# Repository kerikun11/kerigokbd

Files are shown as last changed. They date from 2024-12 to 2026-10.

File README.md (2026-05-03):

# KERIgoKBD (KERI's Ergonomic Keyboard)

けりの自作キーボードの設計データ。

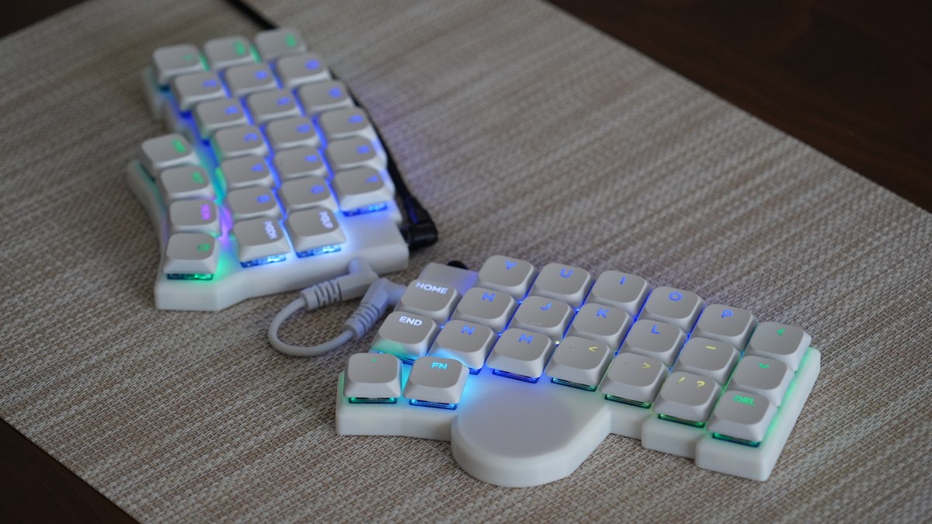
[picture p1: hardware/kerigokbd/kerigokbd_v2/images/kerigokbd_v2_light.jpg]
KERIgoKBD v2


```tree
kerigokbd/
├── hardware/
│   ├── kerigokbd/      # KERIgoKBD common PCB/case parts
│   └── README.md       # Hardware parts and compatibility table
├── software/
│   └── qmk/
│       ├── firmware/   # QMK Firmware for VIA (git submodule)
│       ├── keyboards/  # Keyboard entries for QMK Firmware
│       ├── qmk.sh      # build script
│       └── README.md   # build manual
├── .gitmodules
└── README.md
```

## 作品一覧

ハードウェア部品とファームウェアの対応は [`hardware/README.md`](./hardware/README.md) に記載。

| 作品 | コメント |
| :--- | :--- |
| [KERIgoKBD v1](./hardware/kerigokbd/kerigokbd_v1/) | はじめての自作エルゴノミックキーボード。 |
| [KERIgoKBD v2](./hardware/kerigokbd/kerigokbd_v2/) | KERIgoKBD v1 にトラックパッドを追加した構成。 |
| [KERIgoKBD Corne v4](./hardware/kerigokbd_corne_v4/) | Corne V4 Chocolate のケースとファームウェアをカスタマイズしたもの。 |
| Keyball44 RP2040 | Keyball44 のマイコンボードを RP2040 Pro Micro に差し替えたもの。 |

## KERIgoKBD v1

[けり](https://github.com/kerikun11)のはじめての自作キーボード。

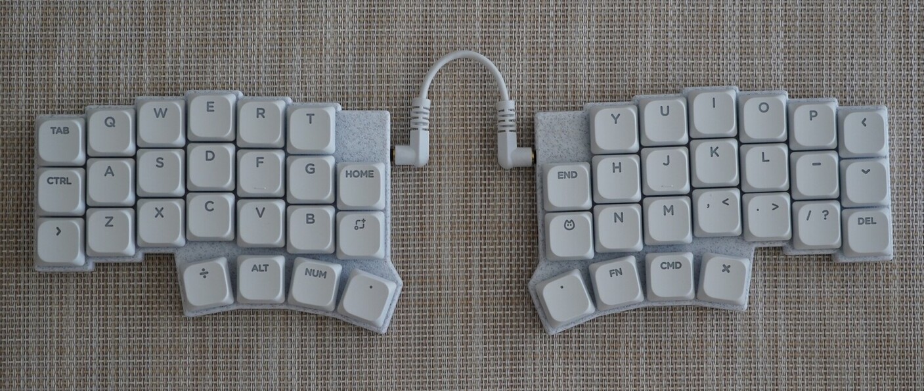
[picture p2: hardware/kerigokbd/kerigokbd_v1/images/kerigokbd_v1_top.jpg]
KERIgoKBD v1


## KERIgoKBD v2

KERIgoKBD v1 の右手側にトラックパッドを追加した構成。

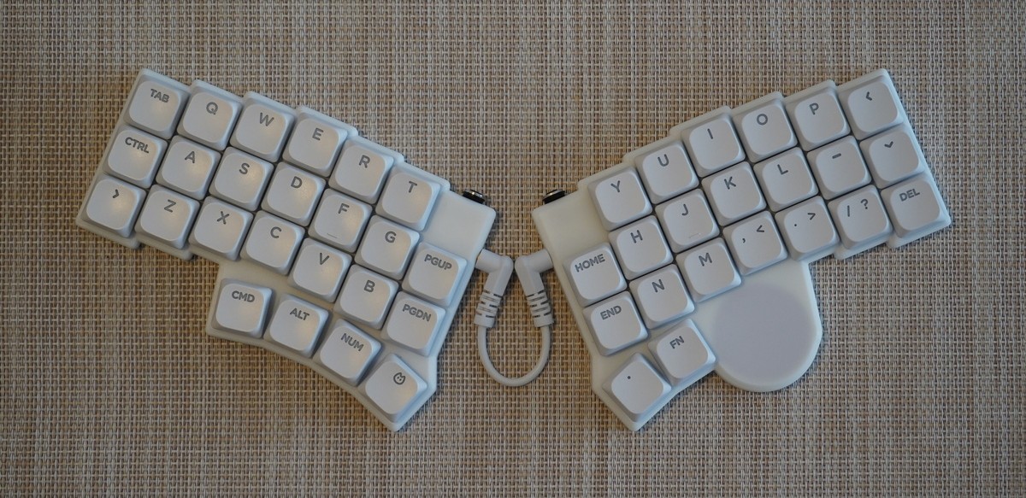
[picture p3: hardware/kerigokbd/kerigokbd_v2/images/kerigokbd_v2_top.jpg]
KERIgoKBD v2


## KERIgoKBD Corne v4

[foostan](https://github.com/foostan)さんの[Corne V4 Chocolate](https://github.com/foostan/crkbd)のケースとファームウェアをカスタマイズしたもの。

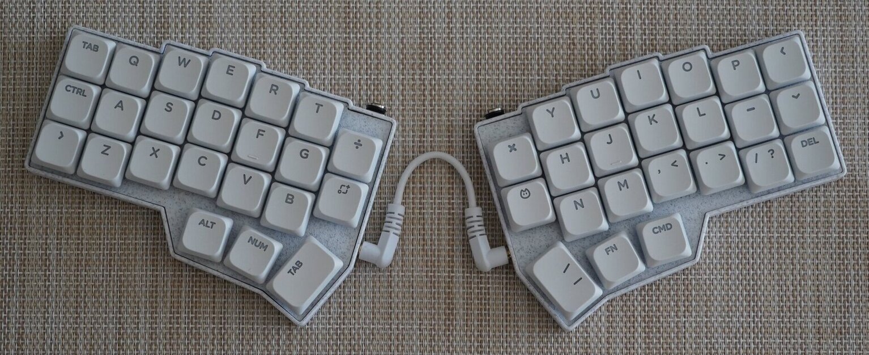
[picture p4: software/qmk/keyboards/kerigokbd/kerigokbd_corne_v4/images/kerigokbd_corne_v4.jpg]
KERIgoKBD Corne V4


## Keyball44 RP2040

[Yowkees](https://github.com/Yowkees)さんの[Keyball44](https://github.com/Yowkees/keyball)のマイコンボードを `RP2040 Pro Micro` に差し替えたもの。

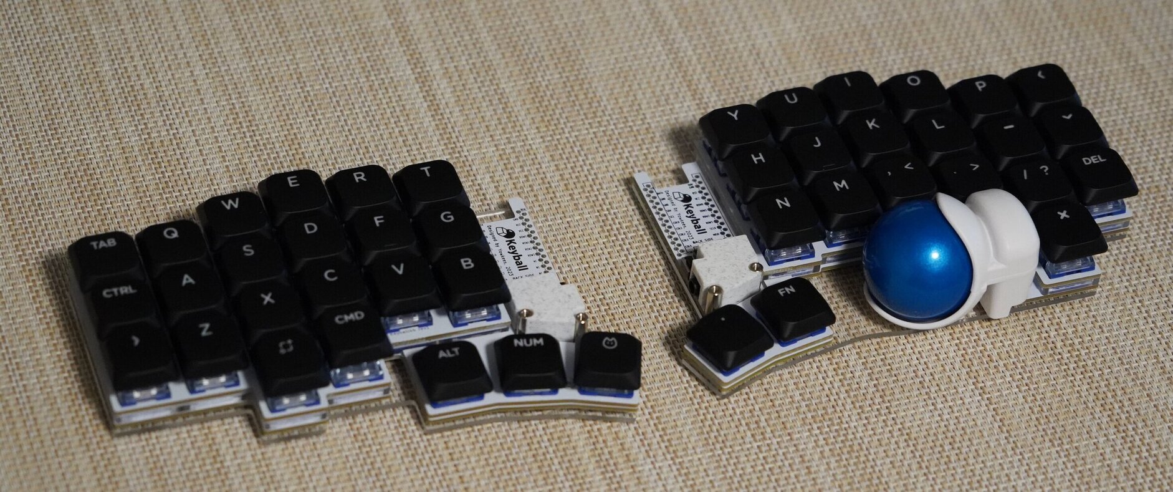
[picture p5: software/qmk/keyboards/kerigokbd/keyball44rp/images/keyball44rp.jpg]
Keyball44rp


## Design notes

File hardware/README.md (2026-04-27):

# Hardware

KERIgoKBD のハードウェア設計データ。ここでは PCB、ケースなどの物理パーツを作品ごとに分離して管理する。

## 対応表

| 作品 | PCB | ケース | ファームウェア | メモ |
| :--- | :--- | :--- | :--- | :--- |
| [KERIgoKBD v1](./kerigokbd/kerigokbd_v1/) | [`pcb_20260222`](./kerigokbd/pcb_20260222/) | [`case_20260222`](./kerigokbd/case_20260222/) | [`kerigokbd_v1`](../software/qmk/keyboards/kerigokbd/kerigokbd_v1) | 標準構成 |
| [KERIgoKBD v2](./kerigokbd/kerigokbd_v2/) | [`pcb_20260222`](./kerigokbd/pcb_20260222/) | [`case_20260222_trackpad`](./kerigokbd/case_20260222_trackpad/) | [`kerigokbd_v2`](../software/qmk/keyboards/kerigokbd/kerigokbd_v2) | 右手にトラックパッド追加 |

## KERIgoKBD パーツ

### PCB

| パーツ | 内容 |
| :--- | :--- |
| [`pcb_20241229`](./kerigokbd/pcb_20241229/) | v1.0 初版。I2Cピンアサインにミスあり。 |
| [`pcb_20250208`](./kerigokbd/pcb_20250208/) | v1.1 I2Cピンアサイン修正版。 |
| [`pcb_20260222`](./kerigokbd/pcb_20260222/) | v1.2 小型版。v1/v2 共通 PCB。 |

### ケース

| パーツ | 内容 |
| :--- | :--- |
| [`case_20250208`](./kerigokbd/case_20250208/) | PCB v1.0 と v1.1 向けのケース。 |
| [`case_20260222`](./kerigokbd/case_20260222/) | PCB v1.2 向けケース。 |
| [`case_20260222_trackpad`](./kerigokbd/case_20260222_trackpad/) | PCB v1.2 向け、トラックパッド対応ケース。 |

## その他

- [`kerigokbd_corne_v4`](./kerigokbd_corne_v4/) は Corne V4 Chocolate のカスタムケース。

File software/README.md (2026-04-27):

# ソフトウェア

ファームウェアのビルドと書き込みの方法

## 前提

- [QMKコマンド](https://docs.qmk.fm/newbs_getting_started)がインストールされていること
- シンボリックリンクが作成できる環境であること

## ソースコードの取得と初回セットアップ

カスタムファームウェアのディレクトリをQMKリポジトリの中にシンボリックで追加して、不要な差分が表示されないように無視設定を行う。

```sh
## clone this repository with submodules
git clone --recursive https://github.com/kerikun11/kerigokbd.git
cd kerigokbd/software
```

下記コマンドでQMK Firmwareの `keyboards` ディレクトリ内へカスタムキーボードへのリンクを作成する。

```sh
## setup only
./qmk/qmk.sh -s
```

## ビルドと書き込み

QMKファームウェアのディレクトリでqmkコマンドを実行する。

```sh
cd ./qmk/firmware
## setup
qmk setup
## clean
qmk clean
## compile
qmk compile -kb kerigokbd/kerigokbd_v1/pcb_20260222 -km via
qmk compile -kb kerigokbd/kerigokbd_v2/pcb_20260222 -km via
## compile and flash
qmk flash -kb kerigokbd/kerigokbd_v1/pcb_20260222 -km via
qmk flash -kb kerigokbd/kerigokbd_v2/pcb_20260222 -km via
```

または下記スクリプトでも実行できる。

```sh
## compile
./qmk/qmk.sh
## compile and flash
./qmk/qmk.sh -f
## clean, compile, and flash
./qmk/qmk.sh -c -f
```

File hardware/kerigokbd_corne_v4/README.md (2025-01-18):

# KERIgoKBD Corne V4



[foostan](https://github.com/foostan)さんの[Corne V4 Chocolate](https://github.com/foostan/crkbd)のケースをカスタマイズしたもの。

## ケース

Autodesk Fusionで設計。Bambu Lab P1S PLA White Marbleで印刷。

- 設計データ(ボトムケース)：[cases](https://github.com/foostan/crkbd/tree/main/cases/3x6) by [foostan](https://github.com/foostan)さん
- 設計データ(フロントパネル)：[case](./case/)

## ライセンス

この作品は [クリエイティブ・コモンズ 表示-非営利 4.0 国際 ライセンス](https://creativecommons.org/licenses/by-nc/4.0/deed.ja)の下に提供されています。

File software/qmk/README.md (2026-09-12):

# ソフトウェア

ファームウェアのビルドと書き込みの方法

## 前提

- [QMKコマンド](https://docs.qmk.fm/newbs_getting_started)がインストールされていること
- シンボリックリンクが作成できる環境であること

## ソースコードの取得と初回セットアップ

カスタムファームウェアのディレクトリをQMKリポジトリの中にシンボリックで追加して、不要な差分が表示されないように無視設定を行う。

```sh
## clone this repository with submodules
git clone --recursive https://github.com/kerikun11/kerigokbd.git
cd kerigokbd/software/qmk
```

下記コマンドでQMK Firmwareの `keyboards` ディレクトリ内へカスタムキーボードへのリンクを作成する。

```sh
## setup only
./qmk.sh -s
```

## ビルドと書き込み

QMKファームウェアのディレクトリでqmkコマンドを実行する。

```sh
cd ./firmware
## setup
qmk setup
## clean
qmk clean
## compile
qmk compile -kb kerigokbd/kerigokbd_v1/pcb_20260222 -km via
qmk compile -kb kerigokbd/kerigokbd_v2/pcb_20260222 -km via
## compile and flash
qmk flash -kb kerigokbd/kerigokbd_v1/pcb_20260222 -km via
qmk flash -kb kerigokbd/kerigokbd_v2/pcb_20260222 -km via
```

または下記スクリプトでも実行できる。

```sh
## compile
./qmk.sh
## compile and flash
./qmk.sh -f
## clean, compile, and flash
./qmk.sh -c -f
```

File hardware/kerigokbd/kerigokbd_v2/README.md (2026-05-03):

# KERIgoKBD v2 Hardware



けりの人間工学キーボード第2版のハードウェア構成。

KERIgoKBD v1.2 PCB を使用し、右手側に Cirque トラックパッドを追加した構成。

KERIgoKBD v2

## 特徴

- 肩への負担を和らげる **左右分離** キーボード
- 手の形に合わせた **カラムスタッガード** の独自キー配置
- 左手24キー、右手22キー、合計46キーの **40%レイアウト**
- レイヤ切り替えに使いやすい **親指キー** を左4個、右2個搭載
- 右手側に **Cirque トラックパッド** を統合
- **ロープロファイルキースイッチ** による薄型・軽量設計
- 全キー **RGB バックライト** でレイヤやキー種別を表示
- **QMK Firmware / VIA / Pointing Device** に対応

KERIgoKBD v2 Top

## 構成

| 項目 | 使用パーツ |
| :--- | :--- |
| PCB | [`pcb_20260222`](../pcb_20260222/) |
| 左手ケース | [`case_20260222`](../case_20260222/) |
| 右手ケース | [`case_20260222_trackpad`](../case_20260222_trackpad/) |
| ファームウェア | [`kerigokbd/kerigokbd_v2/pcb_20260222`](../../../software/qmk/keyboards/kerigokbd/kerigokbd_v2/pcb_20260222/) |
| Keyboard Layout Editor | [KERIgoKBD v2 - Keyboard Layout Editor](https://www.keyboard-layout-editor.com/#/gists/0d82236d0943d0b74055119b50123c59) |

## スペック

| 項目 | 内容 |
| :--- | :--- |
| マイコン | [RP2040](https://www.raspberrypi.com/products/rp2040/specifications/) (Cortex-M0+ 133MHz x2, 264kB SRAM) |
| フラッシュ | [W25Q16JVUXIQ](https://www.digikey.jp/ja/products/detail/winbond-electronics/W25Q16JVUXIQ-TR/) (2MB) |
| キースイッチ | [Kailh Deep Sea Silent Mini Low Profile Key Switch (Linear)](https://www.aliexpress.com/item/1005007364820059.html) |
| キーキャップ | [NuPhy nSA Keycaps (Shine-through White)](https://www.aliexpress.com/item/1005006384968360.html) |
| キーソケット | [Hot Swap Socket for Kailh 1350 Chocolate](https://www.aliexpress.com/item/1005006610157756.html) |
| トラックパッド | [Cirque Trackpad TM035035](https://mou.sr/48nN2VQ) |
| 左右接続ケーブル | [3.5mm AUX Cable (White 3 Pole 10cm)](https://www.aliexpress.com/item/1005002484746676.html) |
| USBケーブル | [USLION Magnetic USB Type-C ケーブル](https://www.aliexpress.com/item/1005006136597761.html) |
| 滑り止めシート | [GRIPLUS ホワイト フリーカット](http://www.amazon.co.jp/dp/B08XHMGPWW/) |

## ライセンス

This work is licensed under a [Creative Commons Attribution-NonCommercial 4.0 International License](https://creativecommons.org/licenses/by-nc/4.0/).

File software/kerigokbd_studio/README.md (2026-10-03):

# KERIgoKBD Studio

- KERIgoKBD v1/v2・KERIgoKBD Corne V4・KERIgoKBD Keyball44の各レイヤーのキーマップを一枚の早見表として表示しつつ、実機に接続した状態でリアルタイムに編集できるWebアプリ(WebHID + QMK VIAプロトコル)。
- GitHub Pagesで公開中: <https://www.kerislab.jp/kerigokbd/>

## 主な機能

- **キーボード切り替え**
  - 設定の「デバイス」にある「キーボード」でv1・v2・Corne V4・Keyball44を切り替え。物理キー配置・トラックパッド有無・Trackpadレイヤー有無も合わせて切り替わる。オートマウスレイヤー(`KGL_AM`)はポインティングデバイスに合わせてv2ではTrackpad、Keyball44ではTrackballと表示する(`build_layout.py`の`label`)
  - 実機に接続すると(ページ読み込み時の自動再接続を含む)、USBのVID/PID(`info.json`/`keyboard.json`の`usb`)から機種を判定して自動で切り替える。未書き込みの変更があるときは破棄してよいか確認する
- **早見表 / 編集画面の切り替え**
  - 設定ペイン右上の「表示 | 編集」で、全レイヤー重ね合わせの早見表(デフォルト表示)と、実機の値を書き換える編集画面を切り替える。接続前はGitHub最新版(mainの`default/keymap.c`、`defaults-*.js`)、接続後は実機の現在の値を表示
  - 設定ペインはモードに合わせて切り替わる。「デバイス」(キーボード選択・接続状態・接続/切断の切り替えボタン・再読込)は共通で、表示モードでは「表示するレイヤー」「書き出し」(PNG)、編集モードでは「書き出し・初期化」(keymap.c・GitHub最新版に更新・初期状態にリセット)を表示する
- **レイヤー別のキーマップ表示**
  - Main/Num/Fn/Extra/Trackpad(v2)・Trackball(Keyball44)の割り当てを1枚の早見表に色分け表示。長押し時の割り当て(Hold)は下端に表示
- **レイヤー表示のON/OFF切り替え**
  - 表示モードの設定「表示するレイヤー」のトグルでNum・Fn・Extra・Trackpadレイヤを個別に表示/非表示にできる。オフにしたレイヤーは凡例と、そのレイヤーを指す長押しラベル(Trackpadはトラックパッド上のアイコンも)からも消える
- **操作アイコン表示**
  - マウスクリック(左/右/中)・ポインタ移動・ホイール移動・スクロールモードをアイコンと凡例で表示
- **実機との同期(WebHID + VIA)**
  - 「実機に接続」で`via`キーマップを書き込んだ実機とペアリングし、現在のキーマップを読み込む
  - 編集画面でキーを選び、キーコードピッカーから値を選ぶと「未書き込みの変更」として保持する(点線表示、レイヤータブにも印)。「実機に書き込む」を押すまで実機には反映されず、レイヤータブ右側の「未書き込み N件」で開く一覧の各キーの「取り消す」(キー単位)・「すべて破棄」、またはピッカーの「このキーの変更を取り消す」で元に戻せる。一覧の項目を押すとそのキーを選択する
  - 編集画面の構成: レイヤータブと変更バー(未書き込み件数・すべて破棄・実機に書き込む)が1行、その下にキーボード、「凡例」、キーコードピッカー。ピッカーは常に同じ位置にあり、未接続・未選択のときは案内を表示する。選択中のキーをもう一度クリックする、キー・ピッカー以外の場所をクリックする、またはEscで選択を解除する
  - 書き込み後は該当レイヤーを実機から読み直して照合し、実機に反映されなかった変更は未書き込みのまま残す
  - 未書き込みの変更がある状態での再読込・キーボード切り替え・ページ離脱は確認を挟む
  - 長押し: ピッカーの「長押し」行で「なし / MO (レイヤーのみ) / LT (タップ+レイヤー) / MT (タップ+修飾キー)」を選ぶ。MO・LTはレイヤーのチップ、MTは修飾キーのチェックボックス(「右側 (R)」で右側)で指定し、選んだ時点で現在のキーに反映される。LT・MTは現在のタップキーをそのまま包み、以降に選んだ基本キーがタップ動作になる。MOはタップ動作を持たないため、キーを選ぶと通常のキーに戻る。TO・DF・TGなどは「レイヤー動作」タブから割り当てる(`TO (Main)` のように動作×レイヤーごとに1ボタン)。今のレイヤーを固定するLayer Lock(`QK_LLCK`)は「特殊」タブから割り当てる(ファームウェアの`LAYER_LOCK_ENABLE = yes`が必要)
  - 同時押し: ピッカーの「同時押し」行のCtrl/Shift/Alt/Winのチェックボックス(「右側 (R)」で右側)で、`LALT(KC_PSCR)`のように修飾キーと同時に送るキーにする。LT・MT・MOとは同時に指定できない(QMKのキーコード仕様)
  - Any: 「Any」タブで16進数(`0x4329`)や`keymap.c`と同じ書式の式(`LT(KGL_EXT, KC_ESC)`・`LALT(KC_PSCR)`・`LCTL_T(KC_A)`・`MT(MOD_LCTL | MOD_LSFT, KC_A)`・`MO(1)`・`KG_ESC`など)を入力して割り当てる。入力中に値と表示を確認でき、不正な式は理由を表示する
  - 編集画面では割り当ての種類を色分けし、凡例に表示する(LT: 青、MO: 紫、TO: 黄土、MT: 緑。修飾キー同時押しは`Ctrl+`のような表記で分かるため色分けしない)
  - キーの交換: キーを選んでピッカー上部の「交換」を押し、交換先のキーをクリックすると、2つのキーの割り当てを入れ替えて未書き込みの変更にする。レイヤータブで切り替えれば別のレイヤーのキーとも交換できる。交換元をもう一度クリック、Esc、または「交換を中止」で取りやめる
  - キーを選ぶと、ピッカー上部の選択中のキー表示に、かっこ書きでそのキーの説明(記号の実際の文字「^」、特殊キーの機能、LT・MTなどのタップ/長押しの動作)を表示する(`keycodes/keycode-description.js`)
  - 編集画面では、GitHub最新版(mainの`default/keymap.c`)から変更されたキーの右上に赤の丸印を表示する
  - 「再読込」で実機の現在値を読み直す。接続中は「実機に接続」ボタンが「切断」に切り替わる
  - 「実機に書き込む」(編集画面の変更バーにあり、未書き込みの変更がないときは押せない。未接続の場合は理由を表示)で未書き込みの変更を実機に反映する
- **左右のキーマップをそろえる**
  - 片側(例: 左)を接続して編集・書き込み後、USBをもう片側(右)に挿し直して「実機に接続」すると、エディタの内容と実機の値が異なる場合に「エディタの内容を残す / 実機の値を読み込む」を確認する
  - 「エディタの内容を残す」を選ぶと差分が未書き込みの変更になり、「実機に書き込む」でその実機に反映される(書き込むまで実機は変更されない)
- **keymap.cへの書き出し**
  - 実機の現在のキーマップから、`keymap.c`に手動で反映できるC言語ソースを生成してコピーする
- **mainの最新版レイアウトへの更新**
  - 選択した機種の`keymaps/default/keymap.c`を数値化したデータ(このページ自身にバンドル済み)で実機の全レイヤーを上書きする。早見表の接続前表示と同じデータなので、更新のためにネットワークへ取得しにいくことはない
  - 実機のファームウェアが報告するレイヤー数より最新版のレイヤー数が多い場合は書き込まない(ファームウェアが古く、mainで追加された新しいレイヤーに未対応な場合など)。少ない場合(v2のファームウェアにv1の最新版を書き込む場合など)は、最新版にあるレイヤーだけを書き込み、実機の残りのレイヤーは変更しない
  - 更新前に実機の値を保存し、書き込み後に再読込して照合する。失敗時は元の値への復元を試み、USB切断などで復元できない場合はその旨を表示する
- **ファームウェア初期状態へのリセット**
  - 実機のファームウェアに組み込まれた初期値に、実機のキーマップを戻す
- **PNG画像エクスポート**
  - 早見表(トグルで隠したレイヤーはそのまま反映)をPNGとしてクリップボードへコピー、またはファイルへダウンロードできる

## 前提条件

- **ブラウザ**: WebHIDに対応したChromium系ブラウザ(Chrome / Edge)。Firefox / Safariは非対応。
- **ファームウェア**: `via`キーマップ(`VIA_ENABLE = yes`)を書き込んだ実機。`default`キーマップにはRAW HIDが無いため接続できない。

VIAのdynamic keymap機能は既定では4レイヤーまでしか公開しない(`quantum/dynamic_keymap.h`の`DYNAMIC_KEYMAP_LAYER_COUNT`既定値)が、KERIgoKBDの`info.json`側で`dynamic_keymap.layer_count`(v2・Keyball44は7、v1・Corne V4は6)を既に指定済みで、QMKのビルド時に`DYNAMIC_KEYMAP_LAYER_COUNT`へ自動変換される(`data/mappings/info_config.hjson`参照)。追加のファームウェア変更は不要。

## 構成

### Webアプリソースコード

- `scripts/`
  - `build_layout.py`: QMK側の`info.json`(Corne V4・Keyball44は`keyboard.json`)・`via.json`から物理配置(座標・matrix)を抽出し`public/generated/layout-*.js`を生成
  - `build_keycodes.py`: QMK本体の正規キーコード定義(`data/constants/keycodes/*.hjson`)と`keymap_japanese.h`・`kerigokbd.h`からキーコード対応表を生成し`public/generated/keycodes.js`を生成
  - `build_defaults.py`: 各機種の`default/keymap.c`をレイヤーごとに数値キーコードへ解決し`public/generated/defaults-*.js`を生成(GitHub最新版との差分表示・早見表の接続前表示・レイアウトバージョン表示・最新版レイアウトへの更新に使用)。レイアウトバージョンは`keymap.c`のGitコミット履歴から`vYYYY.MM.DDa`形式で算出(フルクローンが必要)
- `public/`
  - `index.html`: 画面構造とマウス操作アイコンのSVG `<symbol>`定義
  - `favicon.svg`: 早見表の凡例キーをモチーフにしたページアイコン
  - `styles/`: 画面スタイル(`base.css`: 共通・設定欄・ボタン・ダイアログ、`cheat-sheet.css`: 早見表と凡例、`edit.css`: 編集画面とキーコードピッカー)。PNG出力はページの全スタイルシートを読み込んで埋め込む
  - `app.js`: 画面全体の状態管理・イベント配線
  - `hid/`: WebHID接続(`hid-transport.js`)とVIAプロトコルのエンコード/デコード(`via-protocol.js`)
  - `keycodes/`: 数値キーコードのビット合成式(`keycode-values.js`)、デコード/エンコード(`keycode-codec.js`)、Anyの式パーサ(`keycode-parse.js`)、表示用ラベル(`keycode-format.js`)、対応表(`keycode-registry.js`)、早見表用の複数レイヤー重ね合わせラベル(`cheat-sheet-labels.js`)とマウス操作アイコンの対応表(`cheat-sheet-icons.js`)
  - `layout/`: 生成済み物理配置・デフォルトキーマップの読み込み、USB VID/PIDからの機種判定とWebHIDのデバイスフィルタ
  - `state/`: 状態管理(`keymap-store.js`)、実機同期(`sync-engine.js`)、全レイヤー上書き(`keymap-update.js`)、キーコードピッカーの長押し/同時押し状態の導出(`picker-wrap.js`)
  - `render/`: DOM描画(キーボード表示・早見表と表示レイヤー連動の凡例(`cheat-sheet-panel.js`)・早見表/編集の切り替えボタン・レイヤー表示トグル・PNGボタン・レイヤータブ・キーコードピッカー・未書き込み変更バー・接続バー・ツールバー)
  - `export/`: 実機の現在のキーマップをC言語の`keymaps[][]`ソースへ変換(`c-source-writer.js`)、DOM要素のPNG化(`png-export.js`)と早見表のPNG用カード組み立て(`cheat-sheet-png.js`)
- `tests/`: DOM/WebHIDに依存しない純粋なロジック(プロトコルのバイト列、キーコードのビット合成/分解、C書き出し、状態管理、ピッカーの長押し/同時押し導出)のNode単体テスト

### 生成物

- `public/generated/`: `scripts/`配下の各スクリプトが出力するデータ(`layout-{keyboardId}.js`・`keycodes.js`・`defaults-{keyboardId}.js`)。Gitのコミット対象外

### QMK側の参照ファイル

- `../qmk/keyboards/kerigokbd/`
  - `kerigokbd.h`: レイヤー・キーコードの`#define`定義
  - `kerigokbd_v{1,2}/info.json`・`{kerigokbd_corne_v4,keyball44rp}/keyboard.json`: キー数・マトリクス配置・レイヤー数(`dynamic_keymap.layer_count`)
  - `{kerigokbd_v1,kerigokbd_v2,kerigokbd_corne_v4,keyball44rp}/keymaps/default/keymap.c`: 各レイヤーのデフォルトキー割り当て(`[KGL_MAIN]`のほか`[0]`のような番号指定も可)。Gitコミット履歴からLayoutバージョンも算出
  - `{kerigokbd_v1,kerigokbd_v2,kerigokbd_corne_v4,keyball44rp}/keymaps/via/via.json`: KLE互換の物理キー配置(座標・サイズ)。VIAのレイアウトオプション(Keyball44のボール位置)は機種ごとに`build_layout.py`で選択肢を指定(Keyball44は右ボール)

## 生成

QMKソースコードから`public/generated/`の各ファイルを生成する。

```sh
python3 scripts/build_layout.py
python3 scripts/build_keycodes.py
python3 scripts/build_defaults.py
```

## プレビュー

```sh
python3 -m http.server 8000 --bind 127.0.0.1 --directory public
```

`http://127.0.0.1:8000/`を、WebHID対応ブラウザ(Chrome/Edge)で開く。「実機に接続」から`via`キーマップを書き込んだ実機を選択する。

## テスト

```sh
node --test tests/*.test.js
```

プロトコルのバイト列とキーコードのビット演算は、`kerigokbd_v2`の実際のキーマップ(`KG_ESC = LT(KGL_EXT, KC_ESC)`など)から逆算した値を正解データとしてテストしている。

## 既知の制限

- LT・MT・修飾キー同時押しで包めるのは基本キー(`0x04`〜`0xFF`)のみで、Shift付きの記号(日本語配列の一部など)・マウス/RGB/KERIgoKBD固有キーは選べない(QMKの`LT()`の仕様)。LTで指定できるレイヤーは0〜15。
- 「keymap.cへ書き出し」は実機の現在値から生成するため、未書き込みの変更は含まれない。
- 「keymap.cへ書き出し」機能は、モッドの組み合わせを`LCS()`のような専用マクロではなく`C(S(...))`のようなネストで出力する(生成されるキーコード値は同一だが、表記が手書きの`keymap.c`と異なる場合がある)。Winキーは`LWIN_T()`・`RWIN()`のようにWIN表記で出力する。
- トラックパッド(v2)・トラックボール(Keyball44)が占有する2つのマトリクス位置も、他のキーと同様に通常のキーとして表示・編集できる(物理的にはスイッチが無い位置のため、実用上の意味はない)。
- 「PNGをコピー」はクリップボード書き込みAPI(`navigator.clipboard.write` + `ClipboardItem`)に対応したブラウザ・オリジン(HTTPS/localhost等のセキュアコンテキスト)でのみ動作する。未対応の場合はエラーメッセージを表示するので、「PNGをダウンロード」を使うこと。

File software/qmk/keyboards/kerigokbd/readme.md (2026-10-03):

# KERIgoKBD

KERI's Ergonomic Keyboard

* Keyboard Maintainer: [kerikun11](https://github.com/kerikun11)
* Hardware Supported:
  * [KERIgoKBD v1](../../../../hardware/kerigokbd/kerigokbd_v1/)
  * [KERIgoKBD v2](../../../../hardware/kerigokbd/kerigokbd_v2/)
  * [Corne V4 Chocolate](https://github.com/foostan/crkbd)
  * [Keyball44](https://github.com/Yowkees/keyball) with RP2040 Pro Micro

Make example for this keyboard (after setting up your build environment):

    make kerigokbd/kerigokbd_v1/pcb_20260222:default

    make kerigokbd/kerigokbd_v2/pcb_20260222:default

    make kerigokbd/kerigokbd_corne_v4:default

    make kerigokbd/keyball44rp:default

Flashing example for this keyboard:

    make kerigokbd/kerigokbd_v1/pcb_20260222:default:flash

    make kerigokbd/kerigokbd_v2/pcb_20260222:default:flash

    make kerigokbd/kerigokbd_corne_v4:default:flash

    make kerigokbd/keyball44rp:default:flash

See the [build environment setup](https://docs.qmk.fm/#/getting_started_build_tools) and the [make instructions](https://docs.qmk.fm/#/getting_started_make_guide) for more information. Brand new to QMK? Start with our [Complete Newbs Guide](https://docs.qmk.fm/#/newbs).

## Bootloader

Enter the bootloader in 3 ways:

* **Bootmagic reset**: Hold down the key at Q or P and plug in the keyboard
* **Keycode in layout**: Press the key mapped to `QK_BOOT` if it is available

## KG_WCAD（Win / Ctrl+Alt+Delete）

`KG_LWIN_T_LCTL_LALT_DEL`（別名 `KG_WCAD`、`QK_KB_0`、現在の値は `0x7E00`）は、タップで Ctrl+Alt+Delete、
ホールドで左 Win を送信する。`TAPPING_TERM` や `HOLD_ON_OTHER_KEY_PRESS` は
通常の QMK Mod-Tap と同じ設定が適用される。別のキーを押すとホールド判定になる。

- ファームウェア更新後、VIA の Design タブで対象機種の `keymaps/via/via.json` を読み込み、
  Custom の `KG_WCAD` を任意のキーに割り当てる。Any で `0x7E00` を入力してもよい。
- KERIgoKBD Studio では `KG_WCAD`（Win/CAD）を選ぶ。既存のキー配置は自動変更しない。
- タップ内容は固定。VIA マクロの内容には依存しない。
- 保存値は `QK_KB_0` のまま維持する。内部の Mod-Tap 表現を VIA に登録する必要はない。

実装は共通の `kerigokbd.c` に置く。モデル固有のキー処理を追加する場合は
`process_record_kerigokbd()` を使い、`process_record_kb()` は共通処理に任せる。

回帰テスト（`software/qmk/firmware` で実行）:

```sh
make test:all TEST_LIST=../tests/wcad
```

## KG_ATAB（Alt / Alt+Tab）

`KG_LALT_T_LALT_TAB`（別名 `KG_ATAB`、`QK_KB_1`、`0x7E01`）は、
タップで Alt+Tab、ホールドで左 Alt を送信する。タップごとに Alt も離すため、
ウィンドウ切り替えを1回ずつ行う。切り替え一覧を保持するタイマー処理はない。

更新した VIA 定義の Custom または Studio で `KG_ATAB` を選択する。
VIA の Any では `0x7E01` を使える。既存のキー配置は自動変更しない。
`TAPPING_TERM` と `HOLD_ON_OTHER_KEY_PRESS` は通常の Mod-Tap と同じ設定を使う。

## カスタムキーコードの番号

| 範囲 | 用途 |
|---|---|
| `QK_KB_0` | `KG_WCAD` |
| `QK_KB_1` | `KG_ATAB` |
| `QK_KB_2`〜`QK_KB_9` | 予約 |
| `QK_KB_10` | スクロール |
| `QK_KB_11` | 予約 |
| `QK_KB_12`〜`QK_KB_19` | AutoMouseLayerへ入らないマウス移動／ホイール |

旧番号との互換性・自動移行はない。更新時は保存済みのカスタムキーを再割り当てする。

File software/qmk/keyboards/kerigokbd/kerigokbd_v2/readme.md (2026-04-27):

# KERIgoKBD v2

KERI's Ergonomic Keyboard Version 2 with a Cirque trackpad.

KERIgoKBD v2

* Keyboard Maintainer: [kerikun11](https://github.com/kerikun11)
* Hardware Supported: [KERIgoKBD v2](../../../../../hardware/kerigokbd/kerigokbd_v2/)
* Hardware Availability: Not For Sale

Make example for this keyboard (after setting up your build environment):

    make kerigokbd/kerigokbd_v2/pcb_20260222:default

Flashing example for this keyboard:

    make kerigokbd/kerigokbd_v2/pcb_20260222:default:flash

See the [build environment setup](https://docs.qmk.fm/#/getting_started_build_tools) and the [make instructions](https://docs.qmk.fm/#/getting_started_make_guide) for more information. Brand new to QMK? Start with our [Complete Newbs Guide](https://docs.qmk.fm/#/newbs).

## Bootloader

Enter the bootloader in 3 ways:

* **Bootmagic reset**: Hold down the key at Q or P and plug in the keyboard
* **Keycode in layout**: Press the key mapped to `QK_BOOT` if it is available

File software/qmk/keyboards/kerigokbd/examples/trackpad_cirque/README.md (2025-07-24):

# Cirque Trackpad Example

トラックパッド（タッチパッド）の動作確認用コード。

- マイコンボード: RP2040-Zero
- トラックパッド: TM035035

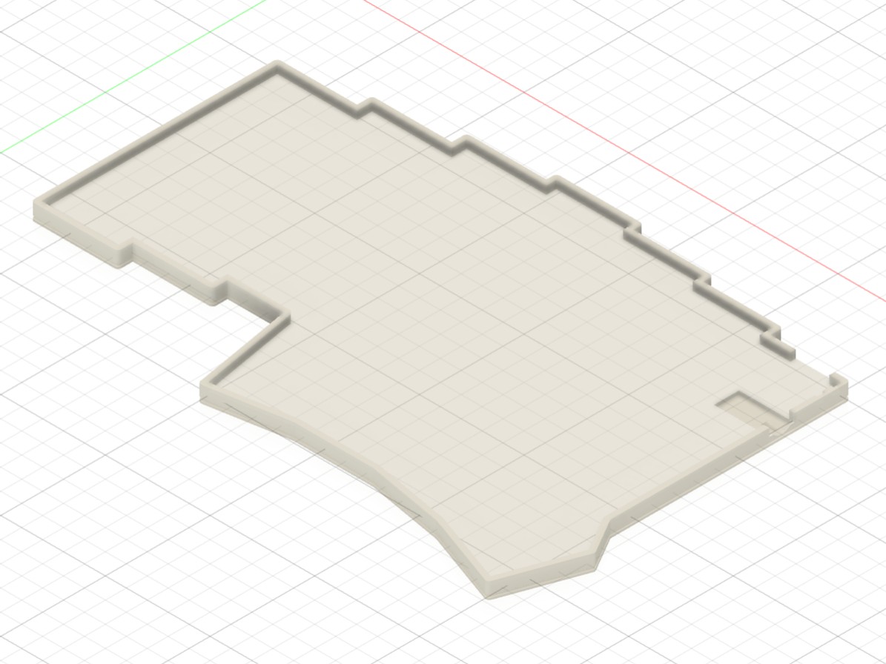
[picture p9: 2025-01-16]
hardware/kerigokbd/case_20250208/images/kerigokbd_v1_case_bottom.jpg

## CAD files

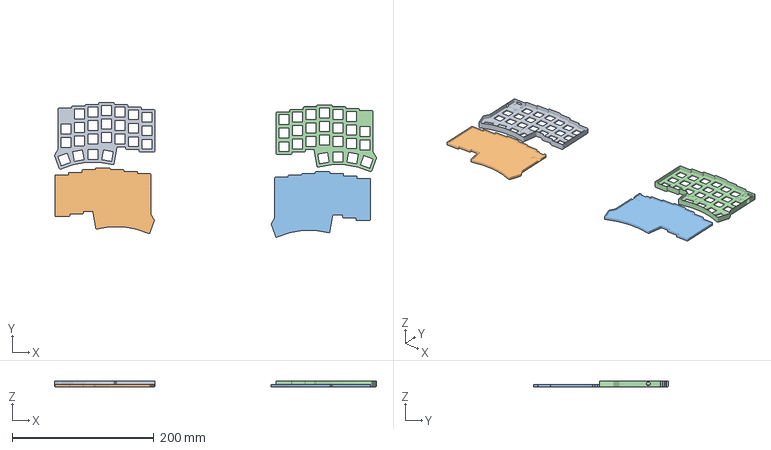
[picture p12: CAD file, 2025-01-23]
hardware/kerigokbd/case_20250208/KERIgoKBD_case.3mf
453.9 x 190.0 x 8.58 mm
KERIgoKBD_case_top.stl x 2
KERIgoKBD_case_bottom.stl x 2

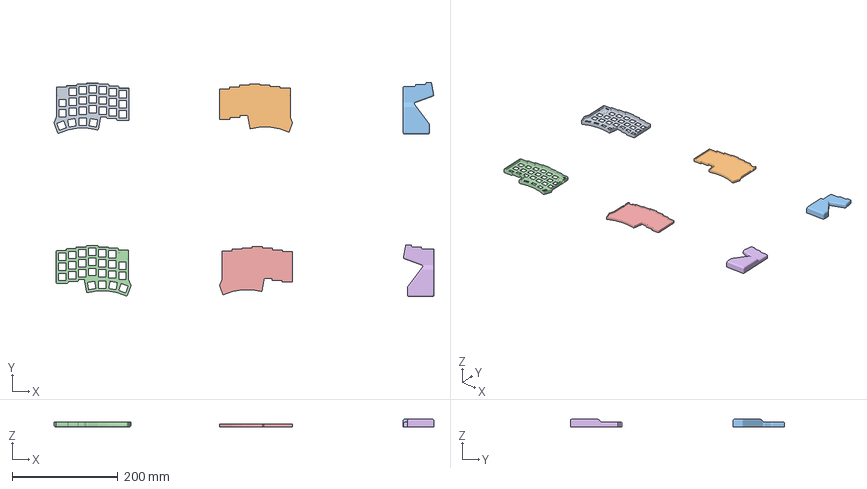
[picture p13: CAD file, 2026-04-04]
hardware/kerigokbd/case_20260222/KERIgoKBD v1.2 case.3mf
717.5 x 404.1 x 15.0 mm
top.stl x 2
bottom.stl x 2
rest.stl x 2

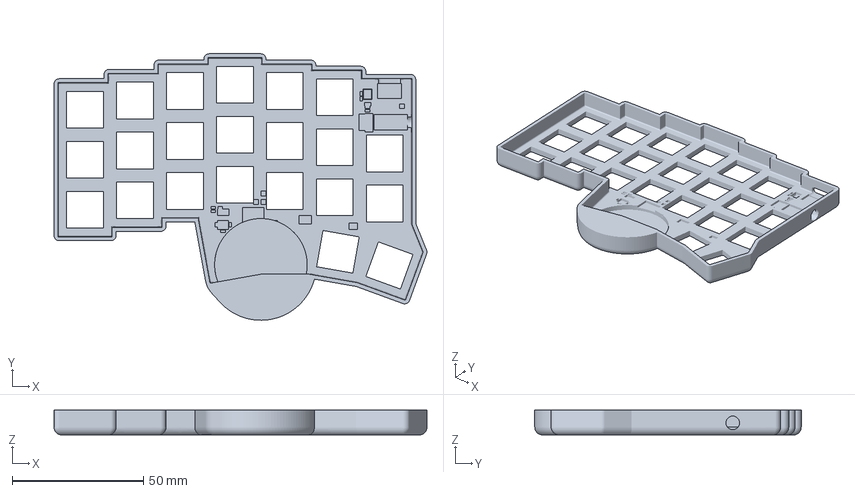
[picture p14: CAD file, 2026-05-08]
hardware/kerigokbd/case_20260222_trackpad/KERIgoKBD v1.2 case with TrackPad35.3mf
141.9 x 101.4 x 9.50 mm

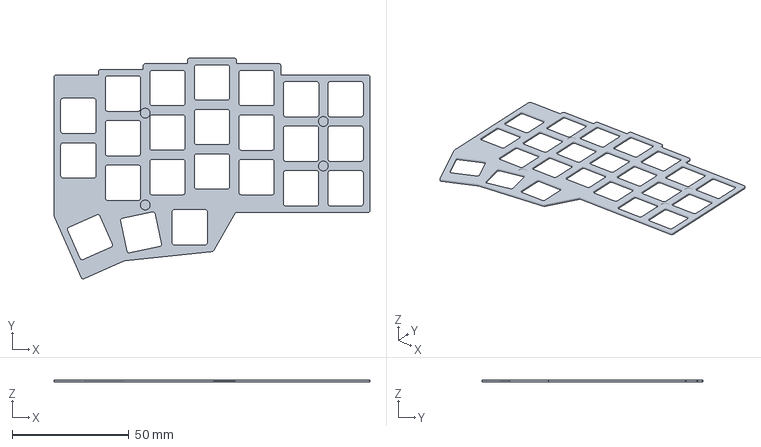
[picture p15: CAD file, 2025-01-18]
hardware/kerigokbd_corne_v4/case/corne_v4_case_top.3mf
135.1 x 94.4 x 1.00 mm

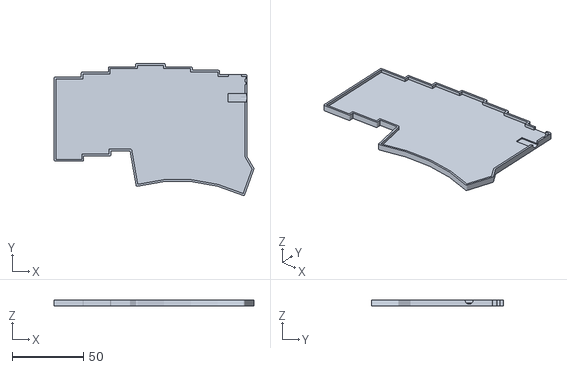
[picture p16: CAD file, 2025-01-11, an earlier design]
hardware/kerigokbd_v1/case/KERIgoKBD_case_bottom.stl
140.1 x 92.6 x 3.90

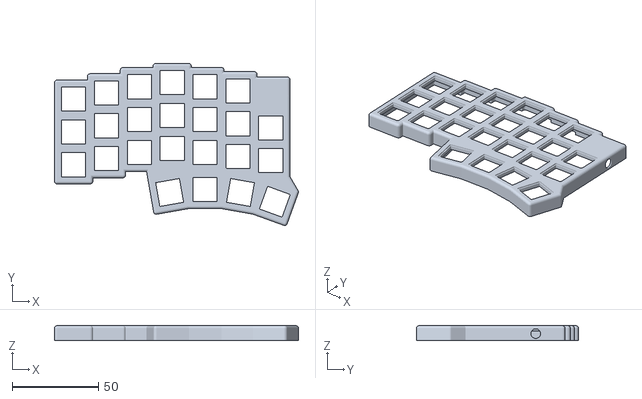
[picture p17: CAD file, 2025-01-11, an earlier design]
hardware/kerigokbd_v1/case/KERIgoKBD_case_top.stl
141.5 x 94.0 x 8.50

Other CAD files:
hardware/kerigokbd/case_20250208/KERIgoKBD_case_bottom.f3d
hardware/kerigokbd/case_20250208/KERIgoKBD_case_top.f3d
hardware/kerigokbd/case_20260222/KERIgoKBD v1.2 case.f3d
hardware/kerigokbd_corne_v4/case/corne_v4_case_top.stl

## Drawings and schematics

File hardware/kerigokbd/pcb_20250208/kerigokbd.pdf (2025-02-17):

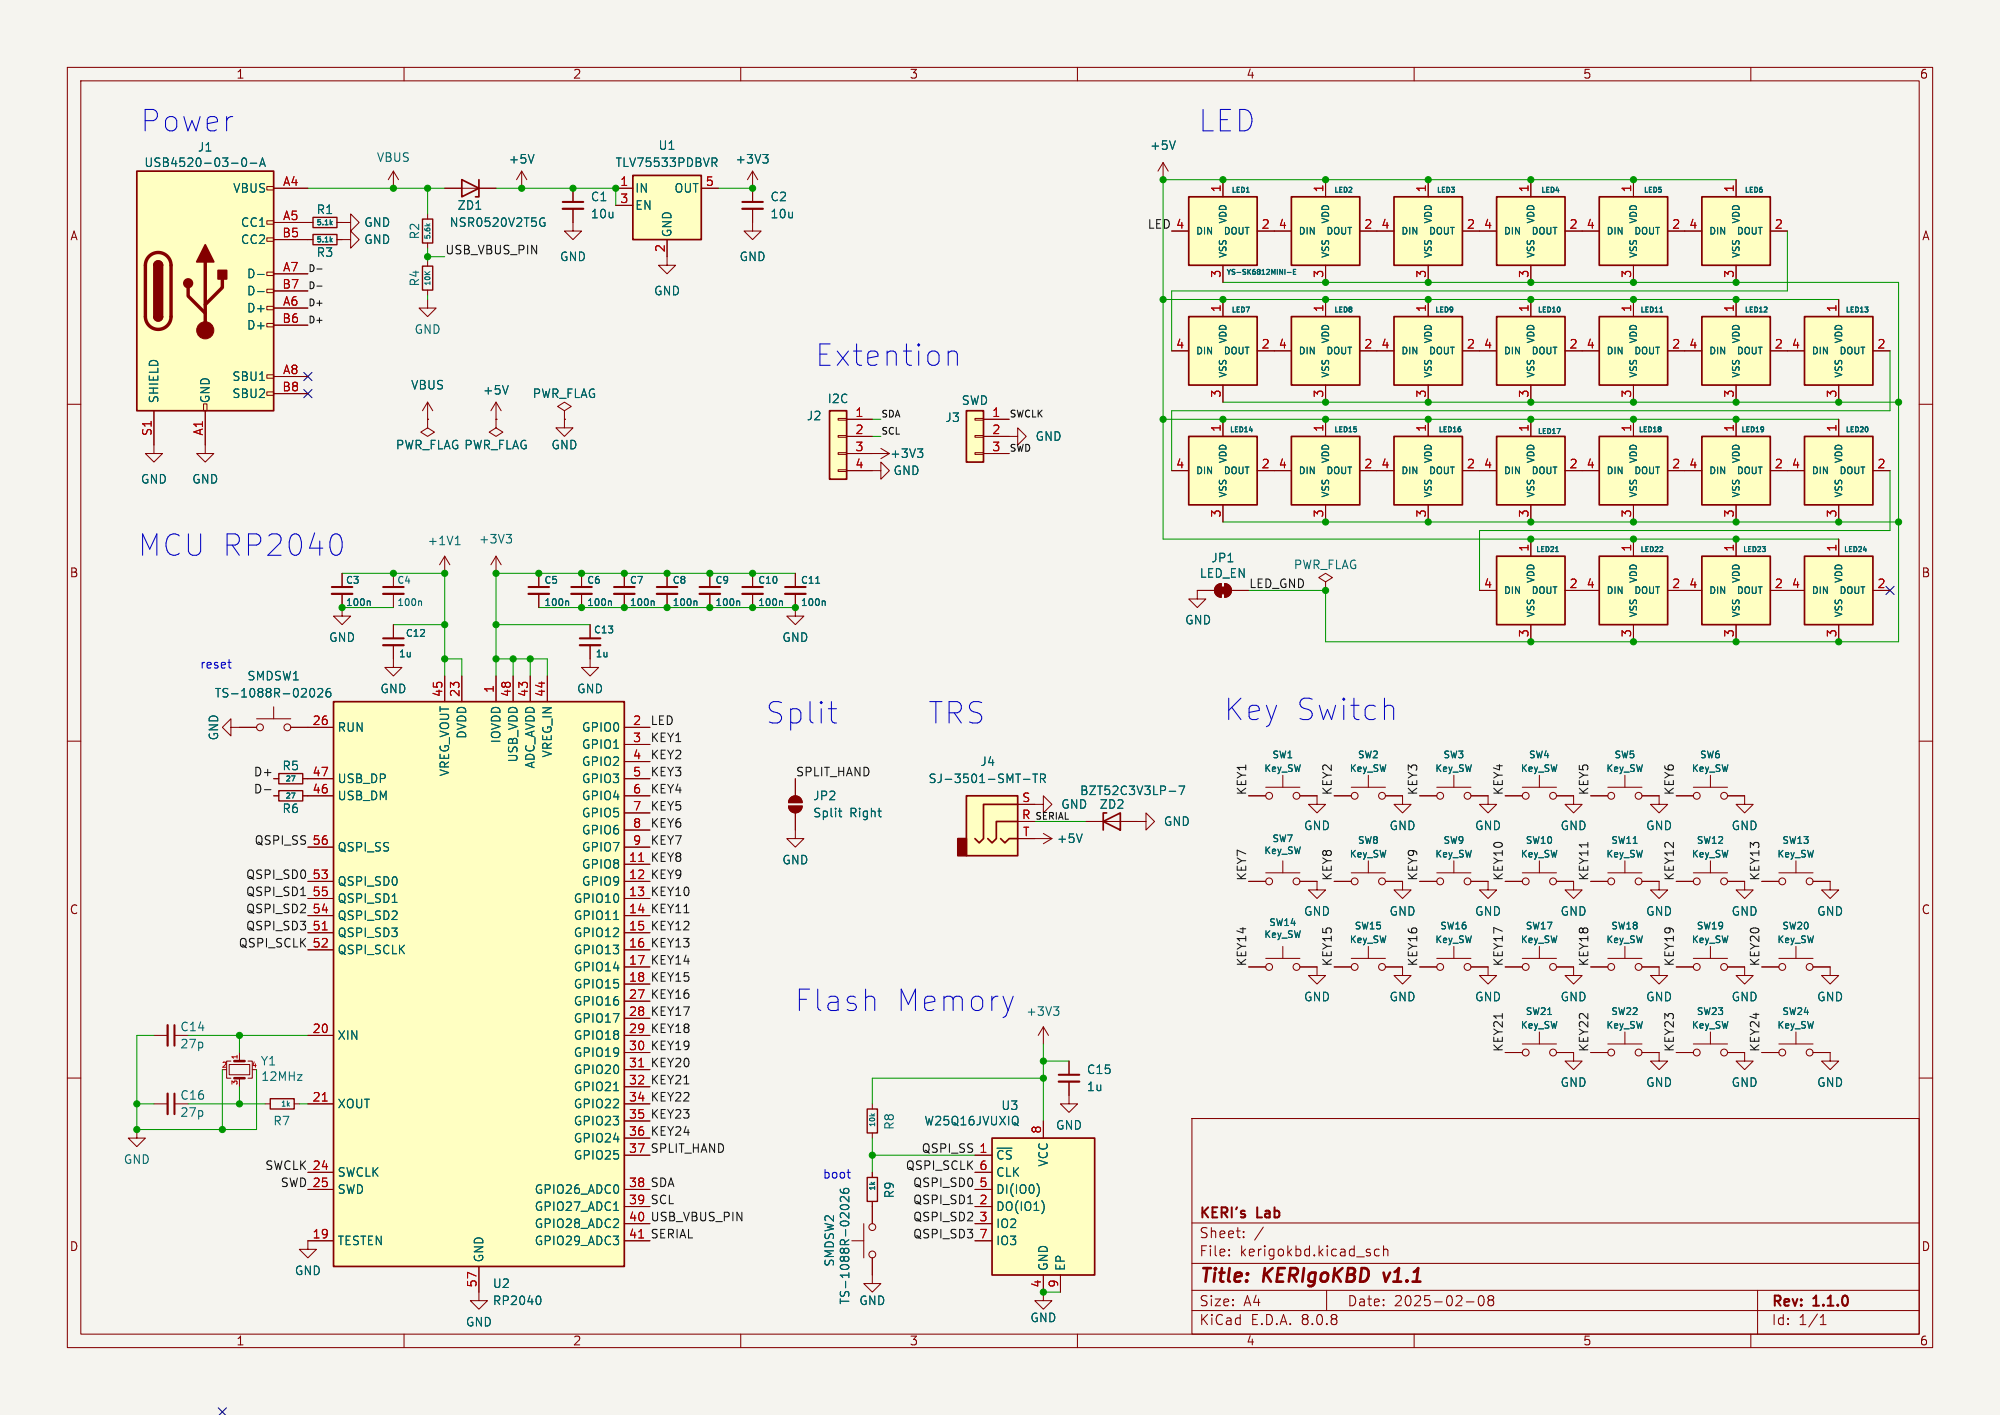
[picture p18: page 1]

1 GPIO8 11 GPIO9 12 GPIO10 13 GPIO11 14 GPIO12 15 GPIO13 16 GPIO14 17 GPIO15 18 TESTEN 19 GPIO0 2 XIN 20 XOUT 21 DVDD 23 SWCLK 24 SWD 25 RUN 26 GPIO16 27 GPIO17 28 GPIO18 29 GPIO1 3 GPIO19 30 GPIO20 31 GPIO21 32 GPIO22 34 GPIO23 35 GPIO24 36 GPIO25 37 GPIO26_ADC0 38 GPIO27_ADC1 39 GPIO2 4 GPIO28_ADC2 40 GPIO29_ADC3 41 ADC_AVDD 43 VREG_IN 44 VREG_VOUT 45 USB_DM 46 USB_DP 47 USB_VDD 48 GPIO3 5 QSPI_SD3 51 QSPI_SCLK 52 QSPI_SD0 53 QSPI_SD2 54 QSPI_SD1 55 QSPI_SS 56 GND 57 GPIO4 6 GPIO5 7 GPIO6 8 GPIO7 9 U2 RP2040 GND GND

1 GPIO8 11 GPIO9 12 GPIO10 13 GPIO11 14 GPIO12 15 GPIO13 16 GPIO14 17 GPIO15 18 TESTEN 19 GPIO0 2 XIN 20 XOUT 21 DVDD 23 SWCLK 24 SWD 25 RUN 26 GPIO16 27 GPIO17 28 GPIO18 29 GPIO1 3 GPIO19 30 GPIO20 31 GPIO21 32 GPIO22 34 GPIO23 35 GPIO24 36 GPIO25 37 GPIO26_ADC0 38 GPIO27_ADC1 39 GPIO2 4 GPIO28_ADC2 40 GPIO29_ADC3 41 ADC_AVDD 43 VREG_IN 44 VREG_VOUT 45 USB_DM 46 USB_DP 47 USB_VDD 48 GPIO3 5 QSPI_SD3 51 QSPI_SCLK 52 QSPI_SD0 53 QSPI_SD2 54 QSPI_SD1 55 QSPI_SS 56 GND 57 GPIO4 6 GPIO5 7 GPIO6 8 GPIO7 9 GND GND

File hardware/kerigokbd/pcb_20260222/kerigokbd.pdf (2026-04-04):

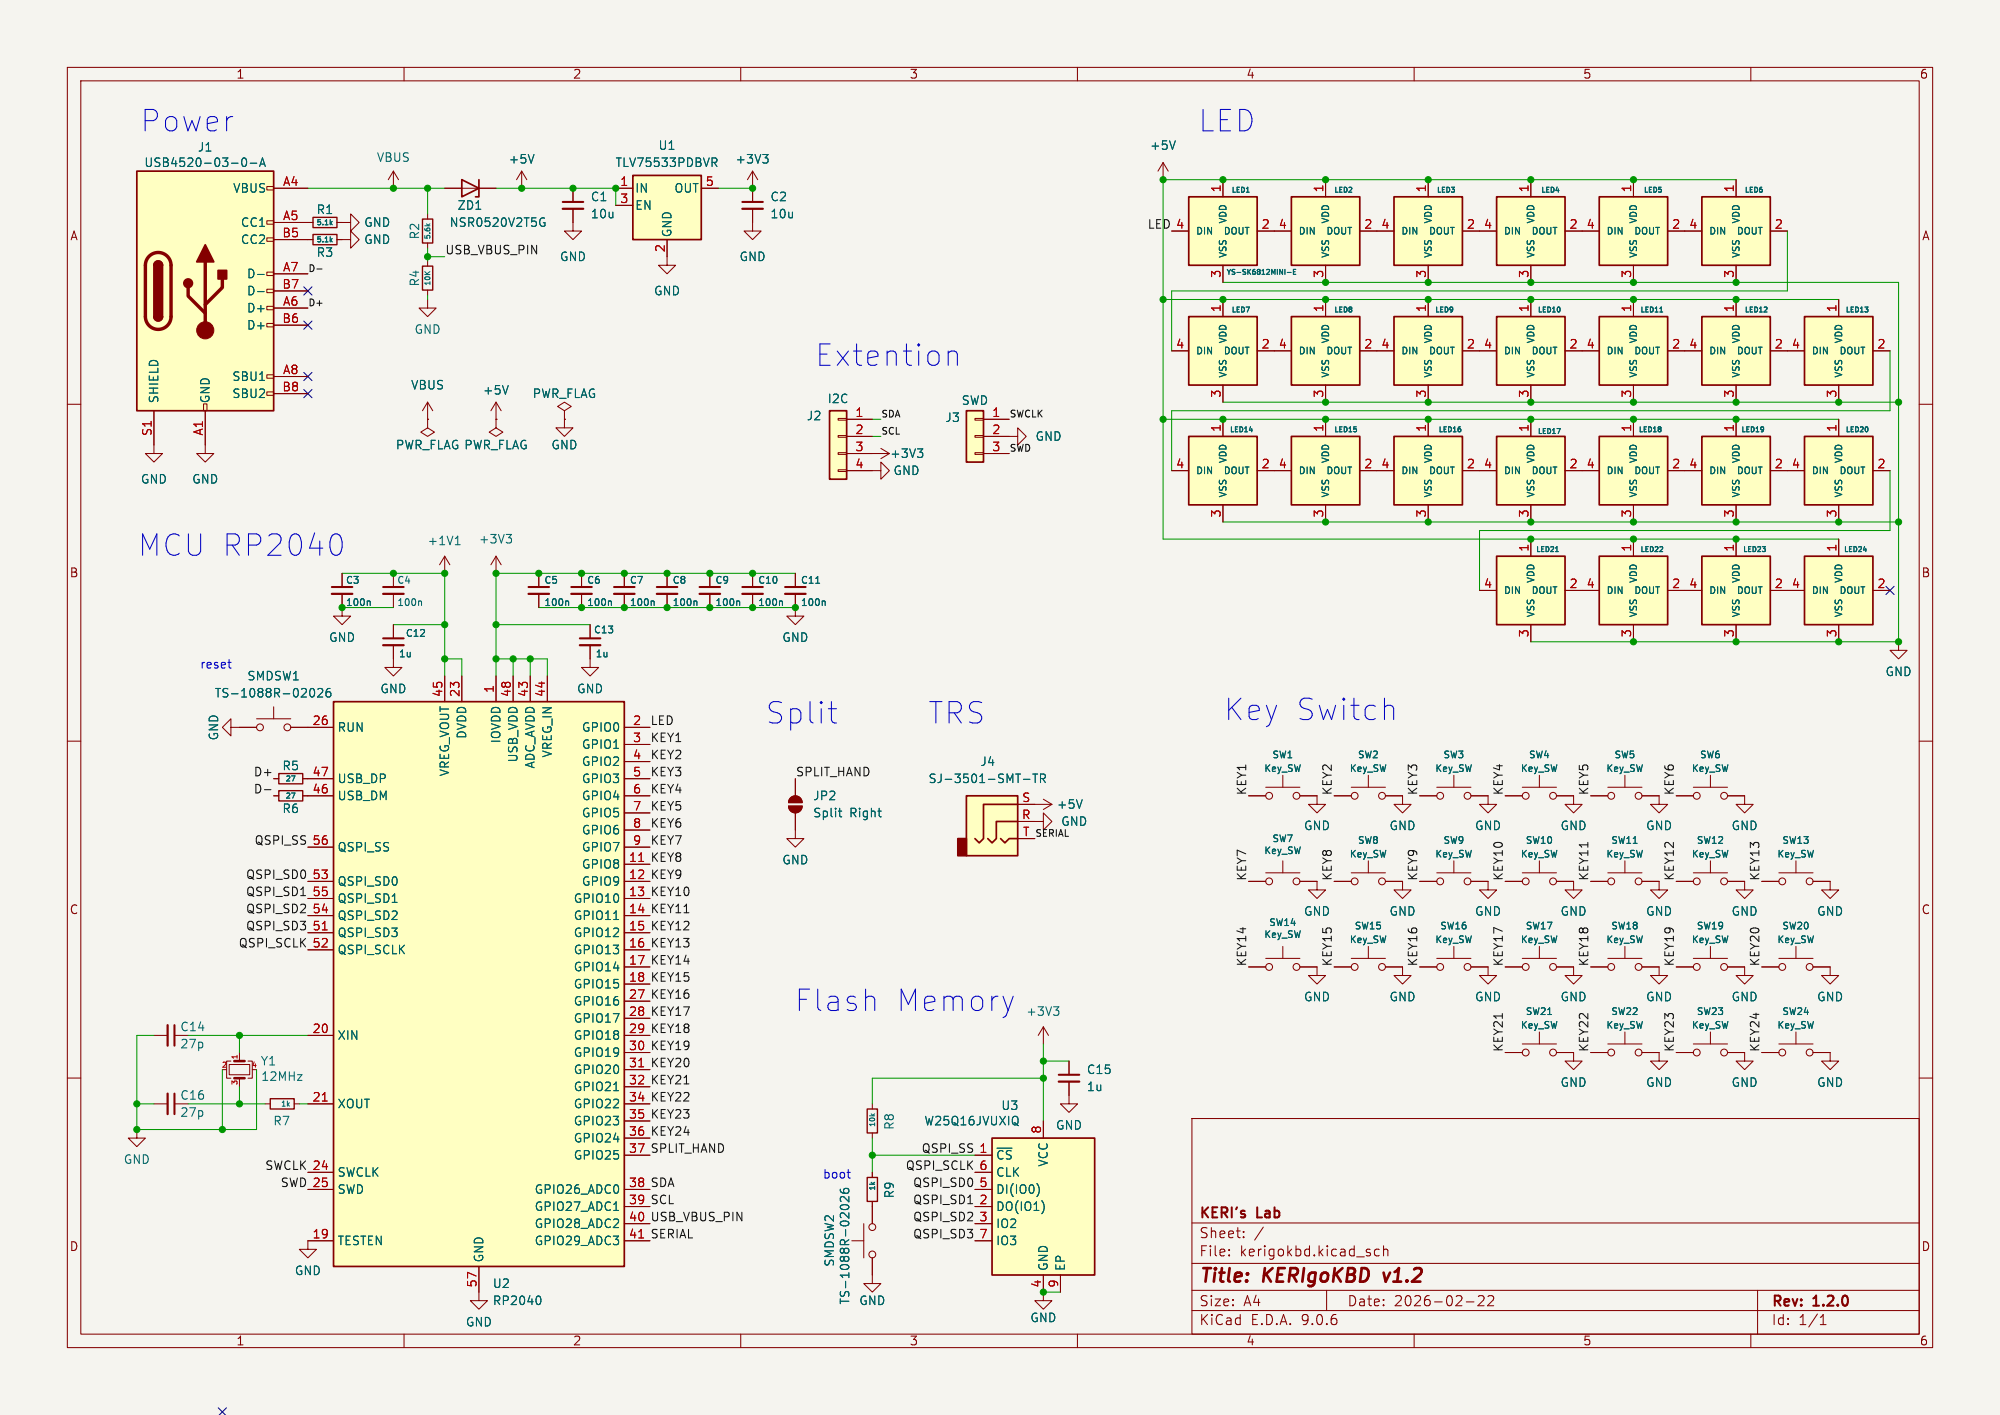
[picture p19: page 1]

~{CS} 1 CLK 6 DI(IO0) 5 DO(IO1) 2

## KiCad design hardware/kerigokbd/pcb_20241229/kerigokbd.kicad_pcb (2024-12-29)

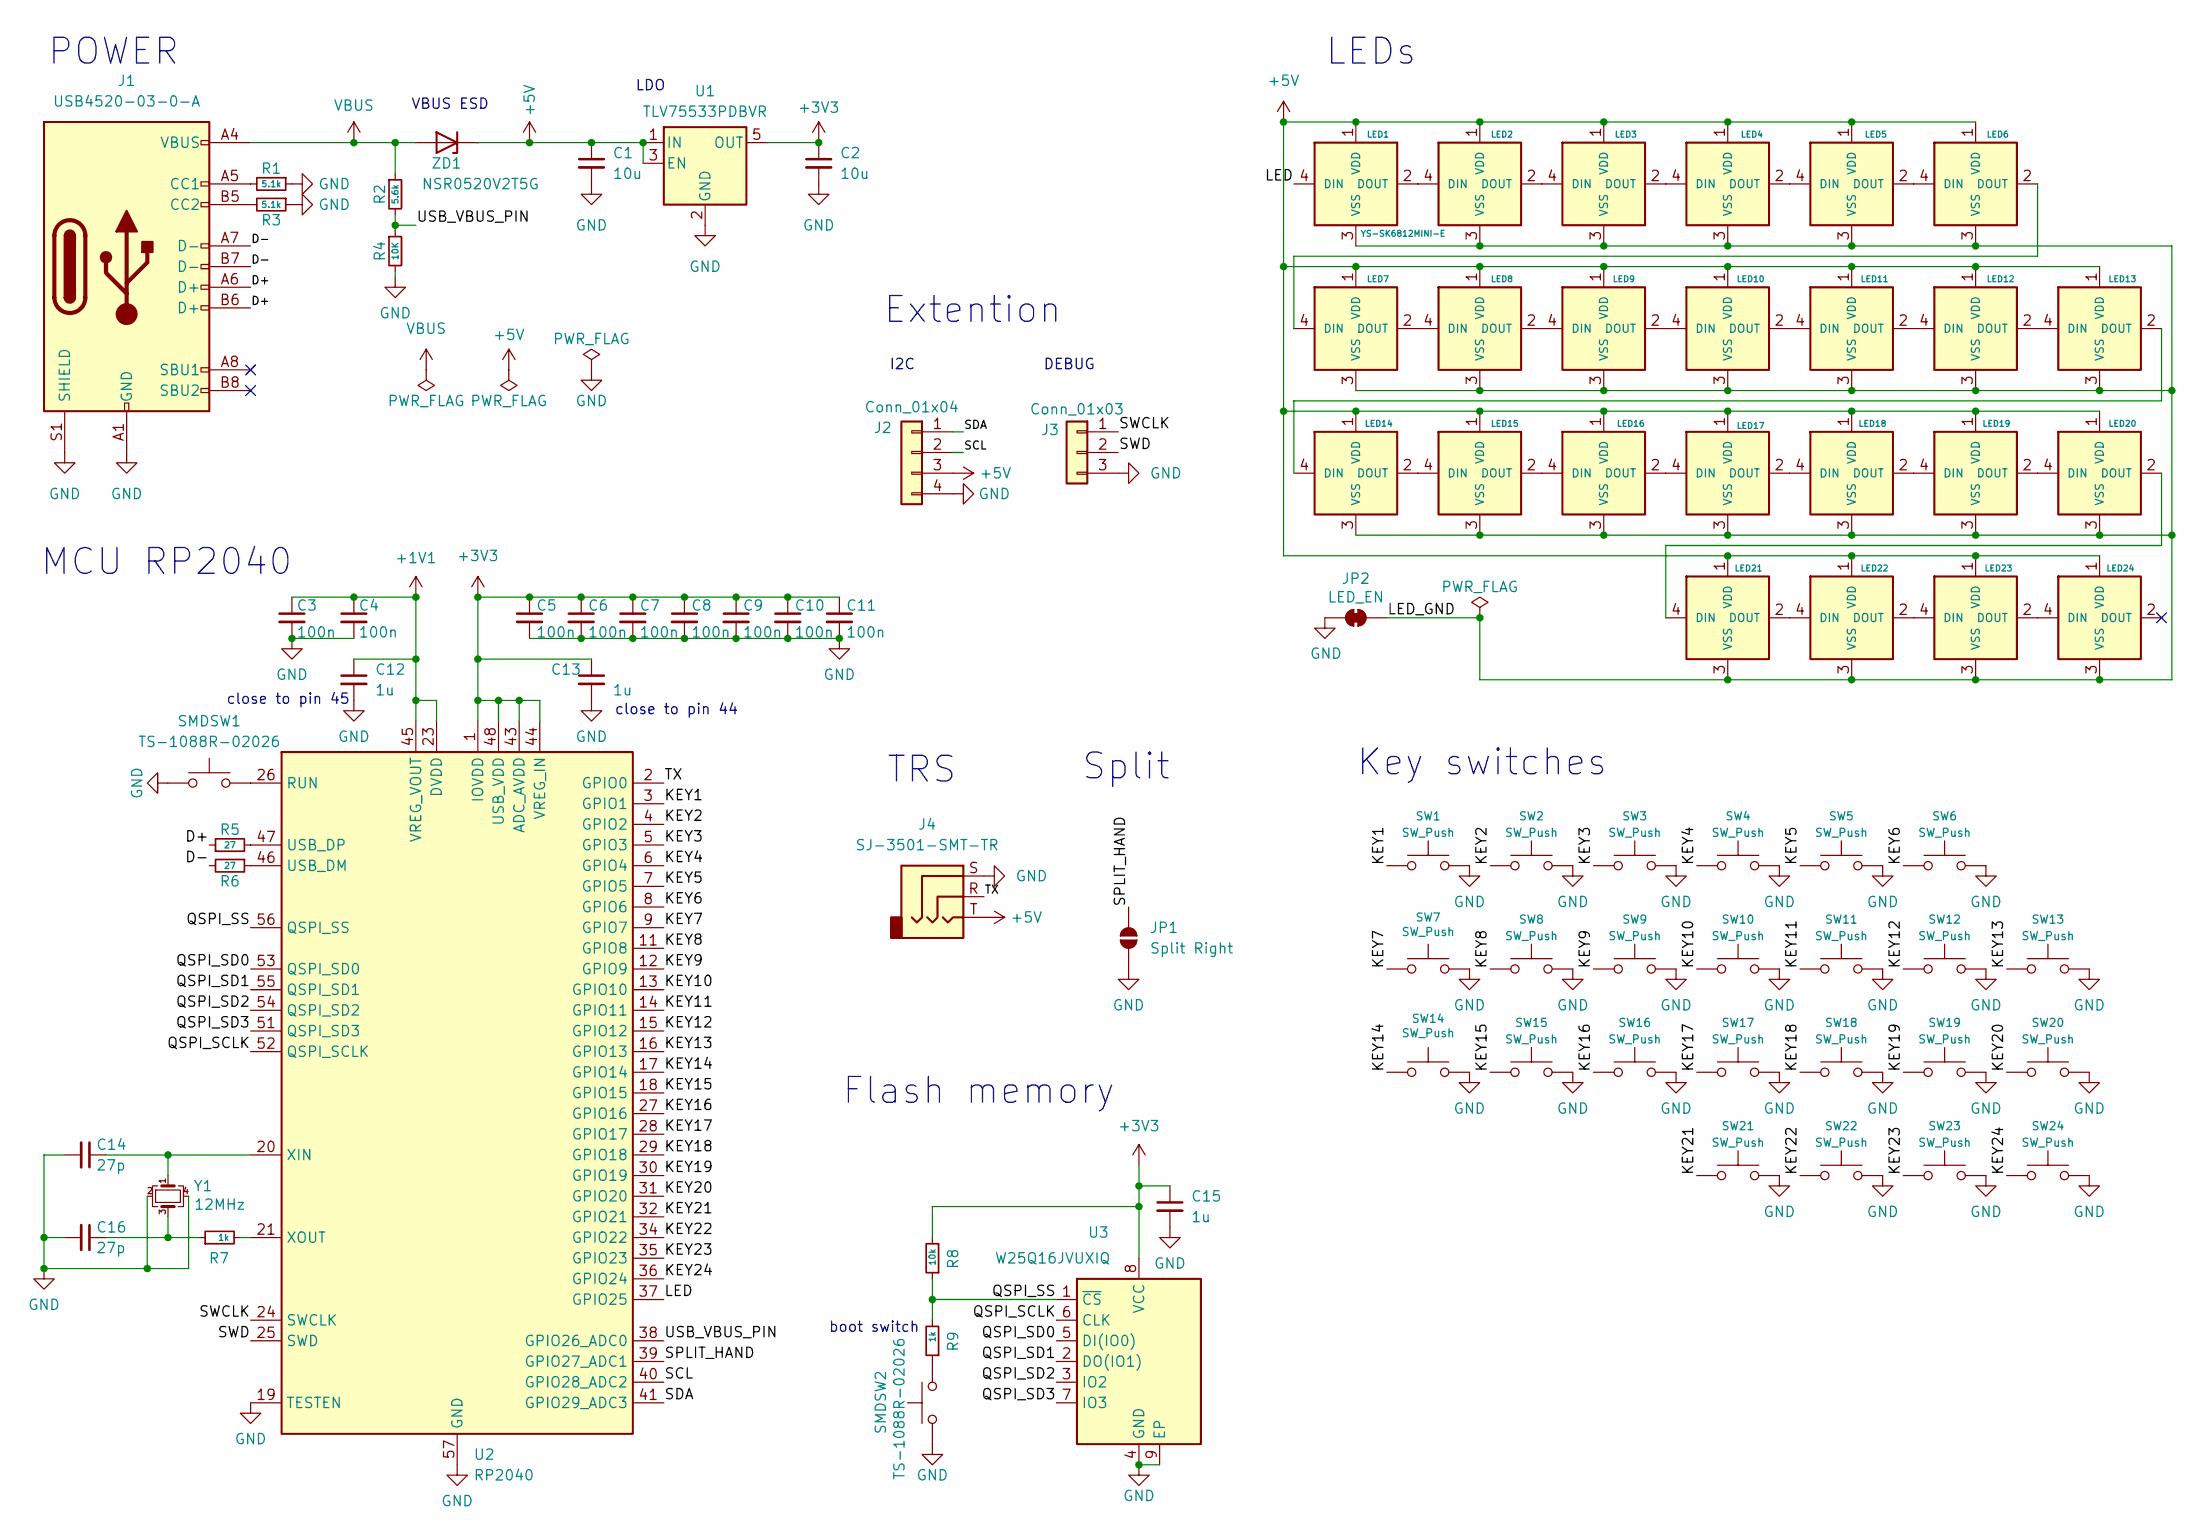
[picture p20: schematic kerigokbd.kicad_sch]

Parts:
C1, C2: 10u; C_0402_1005Metric
C3, C4, C5, C6, C7, C8, C9, C10, C11: 100n; C_0402_1005Metric
C12, C13, C15: 1u; C_0402_1005Metric
C14, C16: 27p; C_0402_1005Metric
J1: USB4520-03-0-A; TYPE-C-31-M-13C-dual; JLCPCB Part # C2848620
J2: Conn_01x04; PinHeader_1x04_P1.27mm_Vertical
J3: Conn_01x03; PinHeader_1x03_P1.27mm_Vertical
J4: SJ-3501-SMT-TR; PJ-398A-5A_PJ-399B-6A-dual; JLCPCB Part # C128994
JP1: Split Right; SolderJumper-2_P1.3mm_Open_TrianglePad1.0x1.5mm
JP2: LED_EN; SolderJumper-2_P1.3mm_Bridged_RoundedPad1.0x1.5mm
LED1, LED2, LED3, LED4, LED5, LED6, LED7, LED8, LED9, LED10, LED11, LED12, LED13, LED14, LED15, LED16, LED17, LED18, LED19, LED20, LED21, LED22, LED23, LED24: YS-SK6812MINI-E; YS-SK6812MINI-E-dual
R1, R3: 5.1k; R_0402_1005Metric
R2: 5.6k; R_0402_1005Metric
R4: 10K; R_0402_1005Metric
R5, R6: 27; R_0402_1005Metric
R7, R9: 1k; R_0402_1005Metric
R8: 10k; R_0402_1005Metric
SMDSW1, SMDSW2: TS-1088R-02026; PinHeader_1x02_P1.27mm_Vertical; JLCPCB Part # C455280
SW1, SW2, SW3, SW4, SW5, SW6, SW7, SW8, SW9, SW10, SW11, SW12, SW13, SW14, SW15, SW16, SW17, SW18, SW19, SW20, SW21, SW22, SW23, SW24: SW_Push; keyswitch_choc12_hotswap_1u_dual
U1: TLV75533PDBVR; SOT-23-5
U2: RP2040; QFN-56-1EP_7x7mm_P0.4mm_EP3.2x3.2mm; JLCPCB Part # C2040
U3: W25Q16JVUXIQ; Winbond_USON-8-1EP_3x2mm_P0.5mm_EP0.2x1.6mm; JLCPCB Part # C113767
Y1: 12MHz; Crystal_SMD_3225-4Pin_3.2x2.5mm; MFR.Part # Q22FA23V0041800; JLCPCB Part # C91749
ZD1: NSR0520V2T5G; D_SOD-523; JLCPCB Part # C145179

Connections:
+1V1: C3.1, C4.1, C12.1, U2.23 (DVDD), U2.45 (VREG_VOUT), U2.50 (DVDD)
+3V3: C2.1, C5.1, C6.1, C7.1, C8.1, C9.1, C10.1, C11.1, C13.1, C15.1, R8.2, U1.5 (OUT), U2.1 (IOVDD), U2.10 (IOVDD), U2.22 (IOVDD), U2.33 (IOVDD), U2.42 (IOVDD), U2.43 (ADC_AVDD), U2.44 (VREG_IN), U2.48 (USB_VDD), U2.49 (IOVDD), U3.8 (VCC)
+5V: C1.1, J2.3, J4.T, LED1.1 (VDD), LED2.1 (VDD), LED3.1 (VDD), LED4.1 (VDD), LED5.1 (VDD), LED6.1 (VDD), LED7.1 (VDD), LED8.1 (VDD), LED9.1 (VDD), LED10.1 (VDD), LED11.1 (VDD), LED12.1 (VDD), LED13.1 (VDD), LED14.1 (VDD), LED15.1 (VDD), LED16.1 (VDD), LED17.1 (VDD), LED18.1 (VDD), LED19.1 (VDD), LED20.1 (VDD), LED21.1 (VDD), LED22.1 (VDD), LED23.1 (VDD), LED24.1 (VDD), U1.1 (IN), U1.3 (EN), ZD1.1 (K)
/D+: J1.A6 (D+), J1.B6 (D+), R5.1
/D-: J1.A7 (D-), J1.B7 (D-), R6.2
/KEY1: SW1.1, U2.3 (GPIO1)
/KEY2: SW2.1, U2.4 (GPIO2)
/KEY3: SW3.1, U2.5 (GPIO3)
/KEY4: SW4.1, U2.6 (GPIO4)
/KEY5: SW5.1, U2.7 (GPIO5)
/KEY6: SW6.1, U2.8 (GPIO6)
/KEY7: SW7.1, U2.9 (GPIO7)
/KEY8: SW8.1, U2.11 (GPIO8)
/KEY9: SW9.1, U2.12 (GPIO9)
/KEY10: SW10.1, U2.13 (GPIO10)
/KEY11: SW11.1, U2.14 (GPIO11)
/KEY12: SW12.1, U2.15 (GPIO12)
/KEY13: SW13.1, U2.16 (GPIO13)
/KEY14: SW14.1, U2.17 (GPIO14)
/KEY15: SW15.1, U2.18 (GPIO15)
/KEY16: SW16.1, U2.27 (GPIO16)
/KEY17: SW17.1, U2.28 (GPIO17)
/KEY18: SW18.1, U2.29 (GPIO18)
/KEY19: SW19.1, U2.30 (GPIO19)
/KEY20: SW20.1, U2.31 (GPIO20)
/KEY21: SW21.1, U2.32 (GPIO21)
/KEY22: SW22.1, U2.34 (GPIO22)
/KEY23: SW23.1, U2.35 (GPIO23)
/KEY24: SW24.1, U2.36 (GPIO24)
/LED: LED1.4 (DIN), U2.37 (GPIO25)
/LED_GND: JP2.2 (B), LED1.3 (VSS), LED2.3 (VSS), LED3.3 (VSS), LED4.3 (VSS), LED5.3 (VSS), LED6.3 (VSS), LED7.3 (VSS), LED8.3 (VSS), LED9.3 (VSS), LED10.3 (VSS), LED11.3 (VSS), LED12.3 (VSS), LED13.3 (VSS), LED14.3 (VSS), LED15.3 (VSS), LED16.3 (VSS), LED17.3 (VSS), LED18.3 (VSS), LED19.3 (VSS), LED20.3 (VSS), LED21.3 (VSS), LED22.3 (VSS), LED23.3 (VSS), LED24.3 (VSS)
/QSPI_SCLK: U2.52 (QSPI_SCLK), U3.6 (CLK)
/QSPI_SD0: U2.53 (QSPI_SD0), U3.5 (DI(IO0))
/QSPI_SD1: U2.55 (QSPI_SD1), U3.2 (DO(IO1))
/QSPI_SD2: U2.54 (QSPI_SD2), U3.3 (IO2)
/QSPI_SD3: U2.51 (QSPI_SD3), U3.7 (IO3)
/QSPI_SS: R8.1, R9.2, U2.56 (QSPI_SS), U3.1 (~CS)
/SCL: J2.2, U2.40 (GPIO28_ADC2)
/SDA: J2.1, U2.41 (GPIO29_ADC3)
/SPLIT_HAND: JP1.2 (B), U2.39 (GPIO27_ADC1)
/SWCLK: J3.1, U2.24 (SWCLK)
/SWD: J3.2, U2.25 (SWD)
/TX: J4.R, U2.2 (GPIO0)
/USB_VBUS_PIN: R2.2, R4.1, U2.38 (GPIO26_ADC0)
GND: C1.2, C2.2, C3.2, C4.2, C5.2, C6.2, C7.2, C8.2, C9.2, C10.2, C11.2, C12.2, C13.2, C14.2, C15.2, C16.2, J1.A1 (GND), J1.A12 (GND), J1.B1 (GND), J1.B12 (GND), J1.S1 (SHIELD), J2.4, J3.3, J4.S, JP1.1 (A), JP2.1 (A), R1.1, R3.1, R4.2, SMDSW1.1, SMDSW2.1, SW1.2, SW2.2, SW3.2, SW4.2, SW5.2, SW6.2, SW7.2, SW8.2, SW9.2, SW10.2, SW11.2, SW12.2, SW13.2, SW14.2, SW15.2, SW16.2, SW17.2, SW18.2, SW19.2, SW20.2, SW21.2, SW22.2, SW23.2, SW24.2, U1.2 (GND), U2.19 (TESTEN), U2.57 (GND), U3.4 (GND), U3.9 (EP), Y1.2, Y1.4
unnamed: C16.1, R7.1, Y1.3
unnamed: J1.A5 (CC1), R1.2
unnamed: J1.B5 (CC2), R3.2
unnamed: LED1.2 (DOUT), LED2.4 (DIN)
unnamed: LED2.2 (DOUT), LED3.4 (DIN)
unnamed: LED3.2 (DOUT), LED4.4 (DIN)
unnamed: LED4.2 (DOUT), LED5.4 (DIN)
unnamed: LED5.2 (DOUT), LED6.4 (DIN)
unnamed: LED6.2 (DOUT), LED7.4 (DIN)
unnamed: LED7.2 (DOUT), LED8.4 (DIN)
unnamed: LED8.2 (DOUT), LED9.4 (DIN)
unnamed: LED9.2 (DOUT), LED10.4 (DIN)
unnamed: LED10.2 (DOUT), LED11.4 (DIN)
unnamed: LED11.2 (DOUT), LED12.4 (DIN)
unnamed: LED12.2 (DOUT), LED13.4 (DIN)
unnamed: LED13.2 (DOUT), LED14.4 (DIN)
unnamed: LED14.2 (DOUT), LED15.4 (DIN)
unnamed: LED15.2 (DOUT), LED16.4 (DIN)
unnamed: LED16.2 (DOUT), LED17.4 (DIN)
unnamed: LED17.2 (DOUT), LED18.4 (DIN)
unnamed: LED18.2 (DOUT), LED19.4 (DIN)
unnamed: LED19.2 (DOUT), LED20.4 (DIN)
unnamed: LED20.2 (DOUT), LED21.4 (DIN)
unnamed: LED21.2 (DOUT), LED22.4 (DIN)
unnamed: LED22.2 (DOUT), LED23.4 (DIN)
unnamed: LED23.2 (DOUT), LED24.4 (DIN)
unnamed: R9.1, SMDSW2.2
unnamed: SMDSW1.2, U2.26 (RUN)
unnamed: R6.1, U2.46 (USB_DM)
unnamed: R5.2, U2.47 (USB_DP)
unnamed: C14.1, U2.20 (XIN), Y1.1
unnamed: R7.2, U2.21 (XOUT)
VBUS: J1.A4 (VBUS), J1.A9 (VBUS), J1.B4 (VBUS), J1.B9 (VBUS), R2.1, ZD1.2 (A)

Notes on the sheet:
Key switches
Extention
LDO
POWER
close to pin 45
Split
VBUS ESD
I2C
boot switch
TRS
LEDs
close to pin 44
Flash memory
MCU RP2040
DEBUG

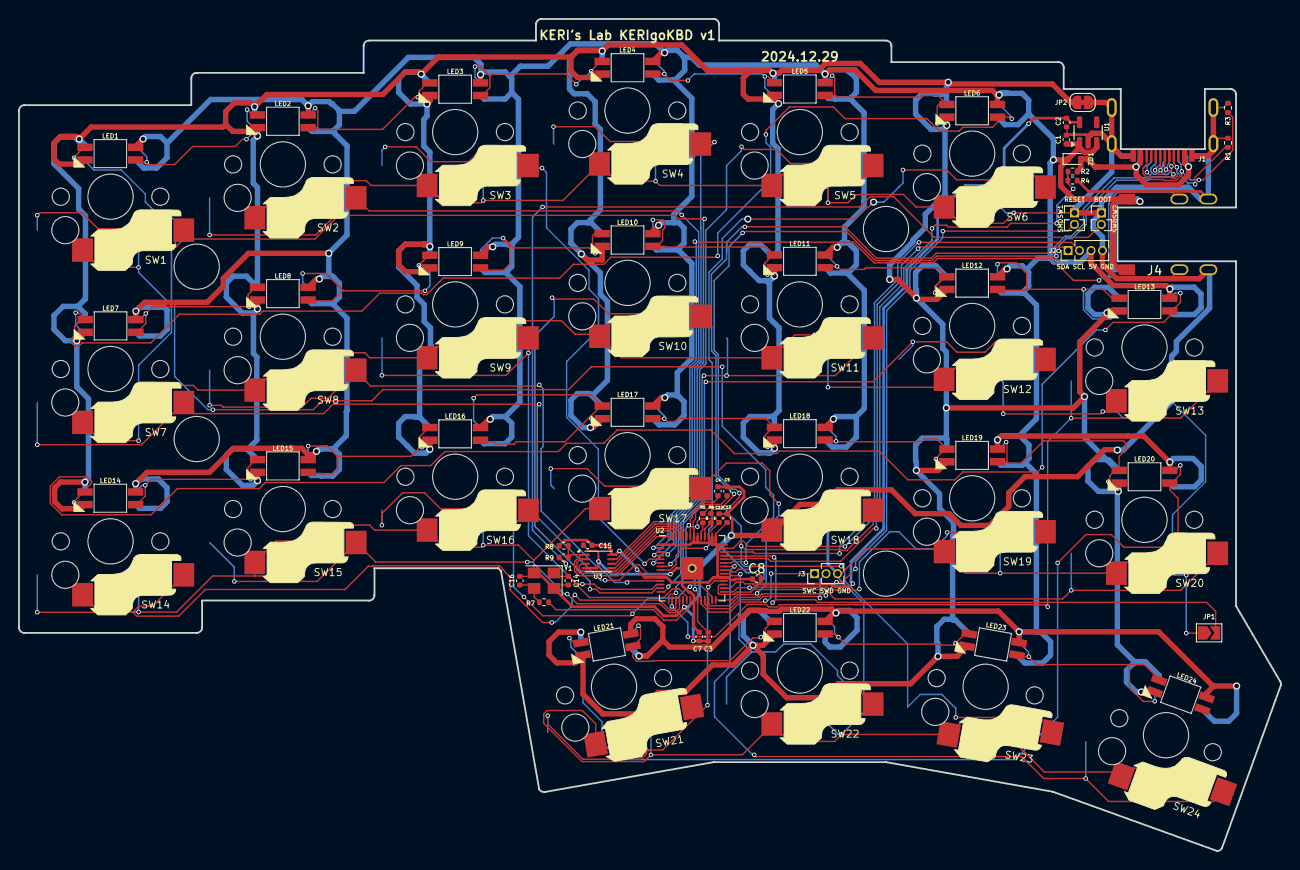
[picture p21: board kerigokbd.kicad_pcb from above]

Board: 2 copper layers, 139.5 x 92.0 mm, 82 parts (0 on the bottom side), 78 nets.

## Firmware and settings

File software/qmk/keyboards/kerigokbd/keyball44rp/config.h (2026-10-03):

// Copyright 2025 KERI's Lab
// SPDX-License-Identifier: GPL-2.0-or-later
// config.h for KERIgoKBD Keyball44

#pragma once

/* SPI */
#define SPI_DRIVER SPID0
#define SPI_SCK_PIN GP22
#define SPI_MISO_PIN GP20
#define SPI_MOSI_PIN GP23

/* Pointing Device */
#define POINTING_DEVICE_CS_PIN GP21
#define POINTING_DEVICE_RIGHT
#define POINTING_DEVICE_INVERT_X
#define POINTING_DEVICE_ROTATION_90

#define POINTING_DEVICE_AUTO_MOUSE_ENABLE
#define AUTO_MOUSE_DEFAULT_LAYER 6 // KGL_AM
#define AUTO_MOUSE_TIME 1000

#define PMW33XX_CPI 1600

/* Split */
#define SPLIT_HAND_MATRIX_GRID_LOW_IS_LEFT
#define SPLIT_POINTING_ENABLE

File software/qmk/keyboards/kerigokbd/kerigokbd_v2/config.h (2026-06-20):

// Copyright 2025 KERI's Lab
// SPDX-License-Identifier: GPL-2.0-or-later
// config.h for KERIgoKBD v2

#pragma once

/* USB */
#define USB_VBUS_PIN GP28

/* I2C */
#define I2C_DRIVER I2CD1 // see https://datasheets.raspberrypi.com/rp2040/rp2040-datasheet.pdf#page=13
#define I2C1_SDA_PIN GP26
#define I2C1_SCL_PIN GP27

/* Pointing Device (https://docs.qmk.fm/features/pointing_device#common-configuration) */
#define SPLIT_POINTING_ENABLE
#define POINTING_DEVICE_RIGHT
#define POINTING_DEVICE_ROTATION_90

/* Auto Mouse Layer */
#define POINTING_DEVICE_AUTO_MOUSE_ENABLE
#define AUTO_MOUSE_DEFAULT_LAYER 6
#define AUTO_MOUSE_TIME 10

/* Cirque Trackpad (https://docs.qmk.fm/features/pointing_device#cirque-trackpad) */
#define CIRQUE_PINNACLE_DIAMETER_MM 35
// #define CIRQUE_PINNACLE_DIAMETER_MM 40
// #define CIRQUE_PINNACLE_ATTENUATION EXTREG__TRACK_ADCCONFIG__ADC_ATTENUATE_1X //< most sensitive
#define CIRQUE_PINNACLE_ATTENUATION EXTREG__TRACK_ADCCONFIG__ADC_ATTENUATE_2X
// #define CIRQUE_PINNACLE_ATTENUATION EXTREG__TRACK_ADCCONFIG__ADC_ATTENUATE_3X
// #define CIRQUE_PINNACLE_ATTENUATION EXTREG__TRACK_ADCCONFIG__ADC_ATTENUATE_4X //< least sensitive

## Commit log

2024-12-07 add encoder
2024-12-12 update LED brightness
2024-12-27 add pcb
    [kerigokbd.kicad_pcb, kerigokbd.kicad_sch]
2024-12-27 update pcb
    [kerigokbd.kicad_pcb]
2024-12-30 mv pcb
    [kerigokbd.kicad_pcb, kerigokbd.kicad_sch, kerigokbd.step]
2024-12-30 add case draft
    [KERIgoKBD_case.3mf, KERIgoKBD_case_bottom.stl, KERIgoKBD_case_top.stl]
2024-12-30 update keyboard.json for new keyboard
    [kerigokbd.3mf]
2024-12-30 update case model
    [KERIgoKBD_case.3mf, KERIgoKBD_case_bottom.stl, KERIgoKBD_case_top.stl]
2024-12-30 update case
    [KERIgoKBD_case.3mf, KERIgoKBD_case_bottom.stl, KERIgoKBD_case_top.stl]
2024-12-30 update dir structure
    [KERIgoKBD_case.3mf, KERIgoKBD_case_bottom.stl, KERIgoKBD_case_top.stl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]
2024-12-30 clean files
    [kerigokbd.3mf]
2025-01-03 add kicad-kbd submodule
2025-01-03 rename kicad kbd
2025-01-03 update kicad 3d path
    [kerigokbd.kicad_pcb, kerigokbd.kicad_sch, kerigokbd.step]
2025-01-03 update KERIgoKBD v1 case
    [KERIgoKBD_case.3mf, KERIgoKBD_case_bottom.stl, KERIgoKBD_case_top.stl]
2025-01-17 update sketch
    [kerigokbd.kicad_sch]
2025-01-18 update docs and images
    [kerigokbd.kicad_sch]
2025-01-18 add case of corne v4
    [corne_v4_case_top.3mf, corne_v4_case_top.stl]
2025-01-23 add fusion model of case
    [KERIgoKBD_case_bottom.f3d, KERIgoKBD_case_top.f3d]
2025-02-02 change serial pin from 0 to 29
2025-02-17 update pin assign to KERIgoKBD v1.1
2025-02-17 support multiple pcb versions
2025-04-11 fix pin assign
2025-06-15 update case models
    [KERIgoKBD_case.3mf, KERIgoKBD_case_bottom.f3d, KERIgoKBD_case_top.f3d]
2026-04-04 update PCB v2026.02.22a
    [kerigokbd.kicad_pcb, kerigokbd.kicad_sch, kerigokbd.step]
2026-04-04 update svg and pdf
    [kerigokbd.kicad_sch]
2026-04-04 update case model for KERIgoKBD v1.2
    [KERIgoKBD v1.2 case.3mf, KERIgoKBD v1.2 case.f3d, KERIgoKBD_case.3mf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]
2026-04-04 promote pcb_20250208 to main
2026-04-04 update device version
2026-04-06 Archive KERIgoKBD v1 hardware revisions
    [KERIgoKBD v1.2 case.3mf, KERIgoKBD v1.2 case.f3d, KERIgoKBD_case.3mf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]
2026-04-13 add pcb_20260222_trackpad
2026-04-27 refactor repository structure
    [KERIgoKBD v1.2 case with TrackPad35.3mf, KERIgoKBD v1.2 case.3mf, KERIgoKBD v1.2 case.f3d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]
2026-09-28 update USB PID for KERIgoKBD v2

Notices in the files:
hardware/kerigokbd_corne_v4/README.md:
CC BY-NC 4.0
